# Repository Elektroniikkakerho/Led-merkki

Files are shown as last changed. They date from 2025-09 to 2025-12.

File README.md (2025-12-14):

# LED-MERKKI
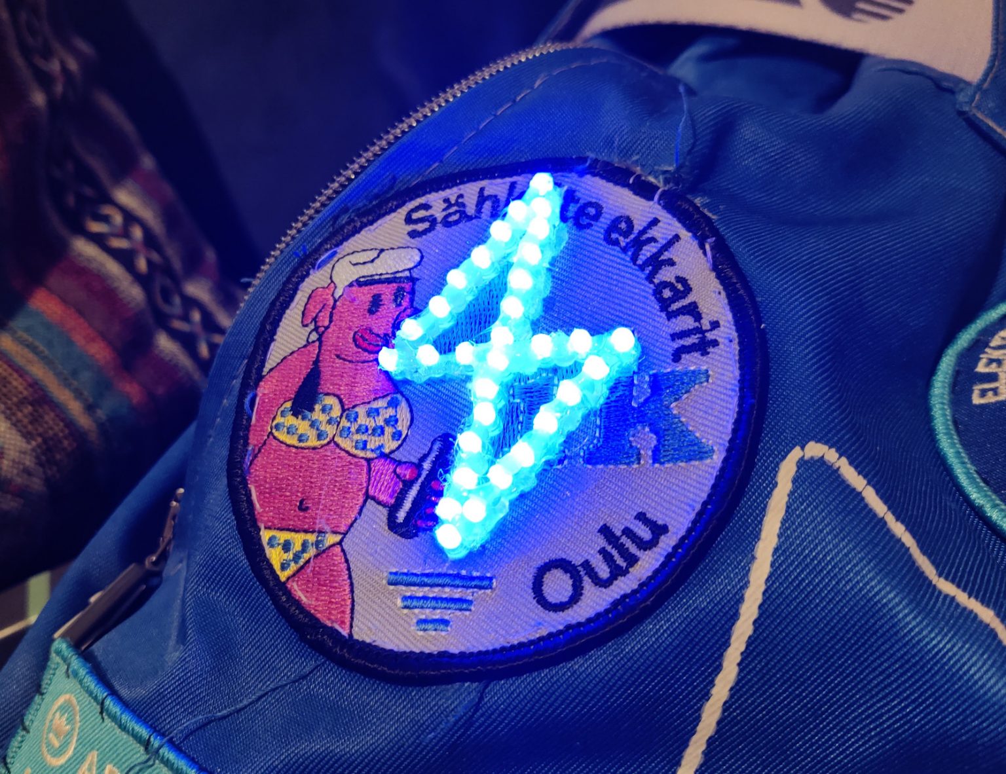
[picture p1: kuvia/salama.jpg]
Tämä kuva vaihtuu joskus gifiin 👀


## Mistä koostuu ja miten se toimii
Salaman mikrokontrolleri (mcu) ohjaa ledejä sytyttäen niitä yksi kerrallaan hyvin lyhyeksi aikaa.
Ledit ovat multiplexattu (4x8 LED), ja kytketty yhdellä vastuksella per rivi.

Levyyn on myös suunniteltu kytkin, jolla voisi vaikka sammuttaa laitteen tai toimittaa muuta toiminnallisuutta, mutta näitä ei ole koodissa toteutettu vieläkään.

Kuusipinninen liitin on ohjelmointia varten ja sitä kautta ohjelma siirretääm mikrokontrollerille.
Ohjelmointi hoituu Arduinon ISP:n kautta.

## Skeema
skeema Skema on jotakuinkin tällainen

## Osaluettelo
<!--
  * 1 kpl  ATtiny861a SOIC
  * 32 kpl 3 mm diffusoitu LED
  * 1 kpl  10 µF SMD tantaalikondensaattori
  * Kuusi pinnisen piikkiriman ohjelmointia varten.

  **Riippuen LEDien väristä:**
  * Siniset/valkoiset/vihreät:   4 kpl 110 Ohm 1206/1210 SMD-vastus
  * Punaiset/keltaiset:          4 kpl 150 Ohm...
  
  **lisäksi tarvitset:**
  * kuumaliimaa
  * USB kaapelin
  * Extra vastuksen? Selivä myöhemmin...
  * haalarimerkin :-)
-->

| **Komponetti** | **KPL** | **Huomautukset** |
| :--- | :--- | :--- |
| ATtiny861a SOIC | 1 |  |
| 3 mm diffusoitu LED | 32 | |
| 110 Ohm 1206/1210 SMD vastus | 4 | Sinisille, valkoisille, vihreille ledeille |
| 169 Ohm 1206/1210 SMD vastus | 4 | Keltaisille, punaisille ledeille |
| 10 µF SMD tantaalikondensaattori | 1 | |
| 6 pinnisen piikkirima | - | Ohjelmointia varten |
| Kuumaliimaa | - | Ledien suojaamiseen |
| USB kaapeli | - | Sopivan pituinen, vaikka 1 m |
| Haalarimerkki | 1 | :-) |

<!---
| **Komponetti** | **KPL** | **Huomautukset** |
| :--- | :--- | :--- |
| ATtiny861a SOIC | 1 | S/SU |
| 3 mm diffusoitu LED | 32 | |
| 10 µF SMD tantaalikondensaattori | 1 | |

| **Vastuksets** | **KPL** | **Huomautukset** |
 :--- | :--- | :--- |
| 110 Ohm 1206/1210 SMD vastus | 4 | Sinisille, valkoisille, vihreille ledeille |
| 150 Ohm 1206/1210 SMD vastus | 4 | Keltaisille, punaisille ledeille |
| | | | 

| **Lisäksi tarvitset** | |
 :--- | :--- |
| 6 pinnisen piikkirima | ohjelmointia varten |
| Kuumaliimaa | Ledien suojaamiseen |
| USB kaapelin | Sopivan pituinen |
| Haalarimerkin  | :-) |
--->
  
## Pirilevyt 
| [SIK](kicad/possu) | OTiT | [YRK](kicad/ymp) | [PROSE](kicad/prose) | [KONE](kicad/kone) | [ARK](kicad/ark) | [OPTIEM](kicad/optiem) |
| :---: | :---: | :---: | :---: |  :---: |  :---: |  :---: |
|   |   |   |  |  |  |  <tr></tr>
|  |  |  |  |  |   | 
<!---| <img src="kicad/kuvat/possu_läpi.svg" alt="alt" width="200">  |   |   |   | | | <tr></tr> --->

<!-- ## Ohjeet piirilevyn tekoon -->
<!-- <details> -->
<!-- <summary><b>Näytä </b></summary> -->
<!-- Tee vaikka syövyttämällä tai jyrsimällä :D -->
<!-- </details> -->

# Ohjeet kokoonpanoon

Nyt kun sinulla on piirilevy, laitetaampa siihen komponentit kiinni.

## 1. Pintaliitos komponentit

Piirilevyyn juotetaan 4 SMD vastusta, 1 SMD kondensaattori ja 6-pinninen piikkirimai.  
Helpointen ja nätein tapa juottaa ne on laittamalla yhteen pädiin vähän tinaa ja sitten     varovasti työntää komponetti sulaneseen tinaan, niin ettei se jää "ilmaan".  
Toinen puoli on helpompi juottaa kun se nyt pysyy siinä paikallaan.

Vastuksilla ei ole väliä kummin päin ne on laitettu, kuhan numero puoli on ylöspäin ja suhteellisen suoraan laitettu, se on hyvä.
Kondensaattorin suunta pitää kattoa leiskasta.

Piikkiriman juottaminen onnistuu samalla tavalla, paitsi nyt joudut pitämään sitä vähän ilmassa,  
jotta saat sen kunnolla juotettua kiinni.

## 2. Piiri 
Piirin juottaminen onnistuu helpointen siten, että juotat ensin yhden kulmajalan kiinni.  
Sulata juotos, jos piiri on vinossa.
Tarkista, että piirin kaikki jalat ovat pädien päällä. Ei ilmassa.  
Juota sitten toinen vastakkainen kulmajalma.

Loput jalat voi juottaa yksi kerrallaan.  
Tai jos haluaa kokeilla nopeammalla tavalla niin veto juottamalla saa yhden puolen yhdellä vedolla*. 
[Esimerkki video...](https://www.youtube.com/results?search_query=drag+soldering)

## 3. Virtajohto
USB kaapelista pitää leikata toinen pää pois.  
Kuori 5v and GND johdot joko saksilla tai kuorimilla.  
Juota sitten 5V ja GND piirilevyyn.

Tähän kannattaa käyttää USB-kaapelia, jossa on vain 5V ja GND.   
Tai sellaista kaapelia jossa on paksut sisäiset johtimet.

## 4. Ledit

Ledien juottaminen on suurin työmaa merkin valmistuksessa.  
Työtä aiheuttaa lähinnä ledin painaminen merkistä läpi. Ensin pitää huomioida polariteetti.  
Jos olet nähnyt paljon vaivaa että olet laittanut ledit miten sattuu niin voipi harmittaa..

**Pidä mielessä:**  
Pyöreä läpiveto ja pidempi jalka ledissä = POS  
Neliö läpiveto ja lyhyempi jalka ledissä = NEG

Ledien jalkojen päät kannattaa katkoa kulmassa, näin niistä tulee teräviä. Helpottaa ledien painamista merkistä läpi.
Toinen kikka on myös paksummalla neulalla tehä reikiä etukäteen.

Jos jostakin syystä, olet juottanut kaikki ledin väärin päin.  
Erinomaista, homma meni pieleen.  
Onneksi on olemassa toinen koodi tiedosto joka vaihtaa ledien logiikan.
   
## [5. Hyppää kohtaan "Ohjelmointi"](#ohjelmointi)
   
## 6. Piikkiriman poisto
Sitten kun ohjelmisto on flashatty ja tarkistettu, että kaikki ledit toimiii niinkuin pitäisi, piikkirima otetaan pois. Joko imusukkaa / tinapumppua käyttäen tai sitten lämmittämällä kaikki joloissa olevat tinat kolvilla, tekemällä vetoliikkeitä.
    
## 7. Kuormavastus 
Tässä kohtaan on hyvä kokeilla laittaa merkki powerbankkiin kiinni.

Jos merkki sammuu itsestään, se voi hyvinkin johtua siitä, että merkki on liian energiatehokas :D
Esim. SIK:in possu merkki syöpi n. 5-20 ma riippuen ledien tilasta.

Tämän ongelman saa korjattua juottamalla kuormavastuksen 5V ja GND väliin.  
Esim. Juottamalla 110 ohmin vastuksen, merkki syö ~60 ma.  
Tarvittava kuormavastus riippuu käyttämästäsi varavirtalähteestä.  
Niissä on vaihteleva minimivirranvaatimus, jonka alittaessa ne katkaisevat virransyötön.
    
## 8. Viimeistely
Lopuksi, laita kuumaliimaa ledien ympärille suojausta varten.  
Ei ole pakko jos et halua.

Mutta siinähän ois ***komia*** merkki valmiina.  
Ei muuta ku ompelemaan kiinni!!  
🥳 🧵 🪡

<!-- </details> -->

# Ohjelmointi

Tähän tarvitset Arduino nanon tai unon, jotta saat siirrettyä koodit levylle.

Koodin kääntämiseen tarvitset avr-gcc ja koodin siirtämiseen avrdude.  
Eli asenna omalle käyttöjärjestelmälle kyseiset työkalut, ennen seuraavia kohtia.

## 1. Ohjelmoinin setuppaus
Aletaanpa pukata sitä koodia, että merkkistä tulisi valoa.  
Mutta ensin pitää hyppyjohdoilla tehdä yhteys led-merkkiin.

Käytetään Arduino nanoa tässä esimerkissä:

| Merkin pinni | 1 | 2| 3 | 4 |5 |6 |
| :---: | :---: | :---: | :---: | :---: | :---: | :---: |
| *Selite* | *MOSI* | *MISO* | *SCK* | *VCC* | *GND* | *Reset* <tr></tr> |
| **Arduinon pinni** | **D11** | **D12**| **D13** | **VCC** | **GND** | **D10** | 

(Leiska kuvasta näkee liittimessä neliön --> 1. pinni)

Muista vetää arduinon Reset ylös. Ardu nollautuu kun sarjaliikenne alotetaan....

## 2. Ledien suunta logiikan flippaus
Mikäli olet juottanut ledit väärinpäin, eikä niiden irroittaminen ja uudelleen juottaminen huvita,  
voit muuttaa ledien ohjaavan logiikan ennen kääntämistä.
      
**Tiedosto: led-merkki/src/vilkutus.c**  
(rivit 6-7):

```c
#include "lediportit.h"             // Mikäli juotit ledit väärin päin,
// #include "lediportit_vaarin.h"   // Vaihda tästä otsikko tiedosto.
  ```
Ledit väärinpäin: 
```c
// #include "lediportit.h"             // Mikäli juotit ledit väärin päin,
#include "lediportit_vaarin.h"   // Vaihda tästä otsikko tiedosto.       
```

## 3. Koodin kääntäminen

```bash
# Kääntäminen käyttäen avr-gcc:tä
avr-gcc -mmcu=attiny861 salama.c -I./ -Os -DF_CPU=8000000UL
```

  Jos et saa koodeja käännettyä,  pre_compiled hakemistosta löytyy valmiiksi käännetyt koodit. 
    
## 4. Ohjelman siirto levylle 

#####  Unix-like

```bash
# Fläsäys käyttäen arduino-isp:tä
avrdude -c avrisp -p t861 -B3 -P /dev/ttyUSB0 -b 19200 -U flash:w:a.out

# Fuse asetukset käyttäen arduino-isp:tä
avrdude -c avrisp -p t861 -B3 -P /dev/ttyUSB0 -b 19200 -U lfuse:w:0xe2:m -U hfuse:w:0xdf:m
```
Jos valittaa oikeuksista, vedä sudo/doas tilassa.

Jos siirtämisen aikana tulee "programmer not responding",  
kokeile toista baudratea tai ottamalla "-B3" pois.

##### Windows

```bash
# Fläsäys käyttäen arduino-isp:tä
avrdude -C "C:\Program Files (x86)\Arduino\hardware\tools\avr\etc\avrdude.conf" -c avrisp -p t861 -B3 -P COM7 -b 19200 -U flash:w:a.out

# Fuse asetukset käyttäen arduino-isp:tä
avrdude -C "C:\Program Files (x86)\Arduino\hardware\tools\avr\etc\avrdude.conf" -c avrisp -p t861 -B3 -P COM7 -b 19200 -U lfuse:w:0xe2:m -U hfuse:w:0xdf:m
```
Windowsilla avrdude pitää olla ympäristömuuttujissa.  
Toinen vaihtoehto on ajaa komento "\Arduino\hardware\tools\avr\bin"-kansiossa.

## [5. Hyppää kohtaan "Piikkiriman poisto"](#6-piikkiriman-poisto)

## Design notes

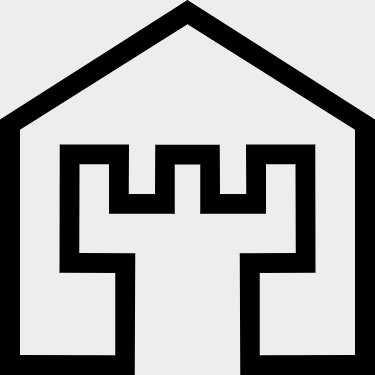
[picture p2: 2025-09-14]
kicad/ark/ark.bmp

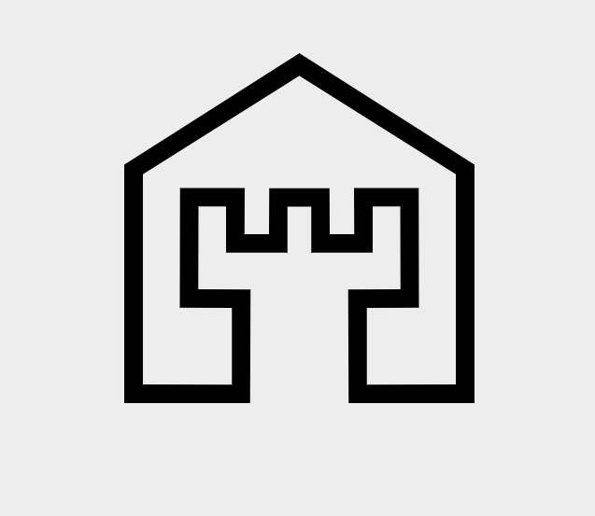
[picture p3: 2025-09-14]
kicad/ark/ark.png

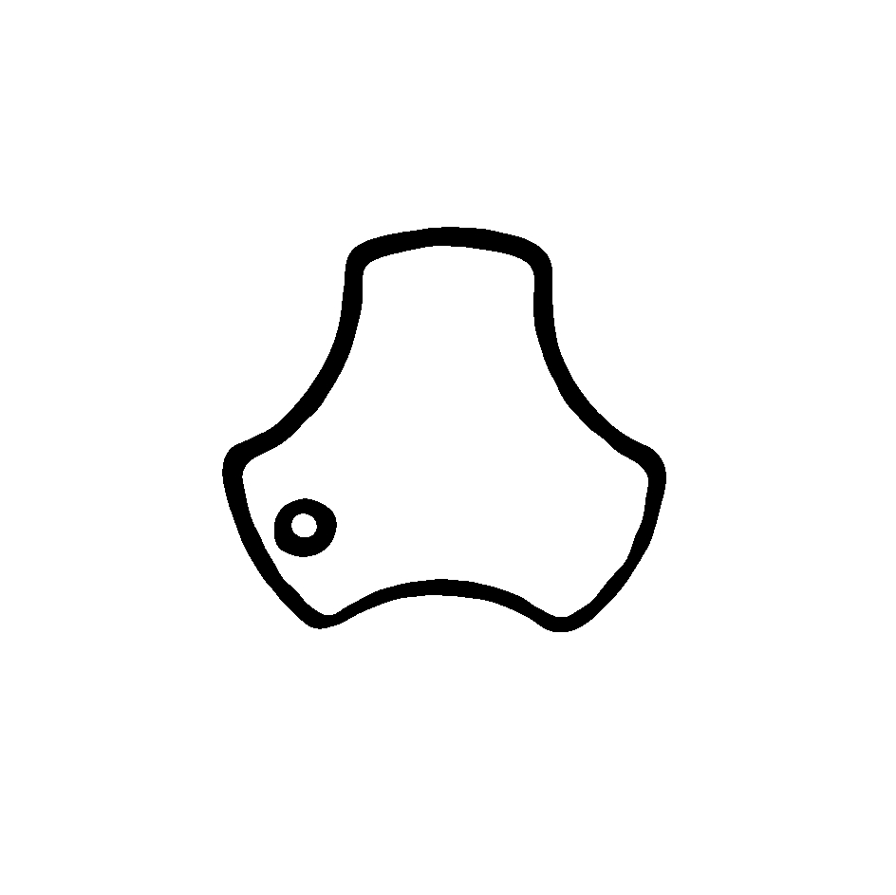
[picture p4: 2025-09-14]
kicad/kone/konekiltauusi.jpeg

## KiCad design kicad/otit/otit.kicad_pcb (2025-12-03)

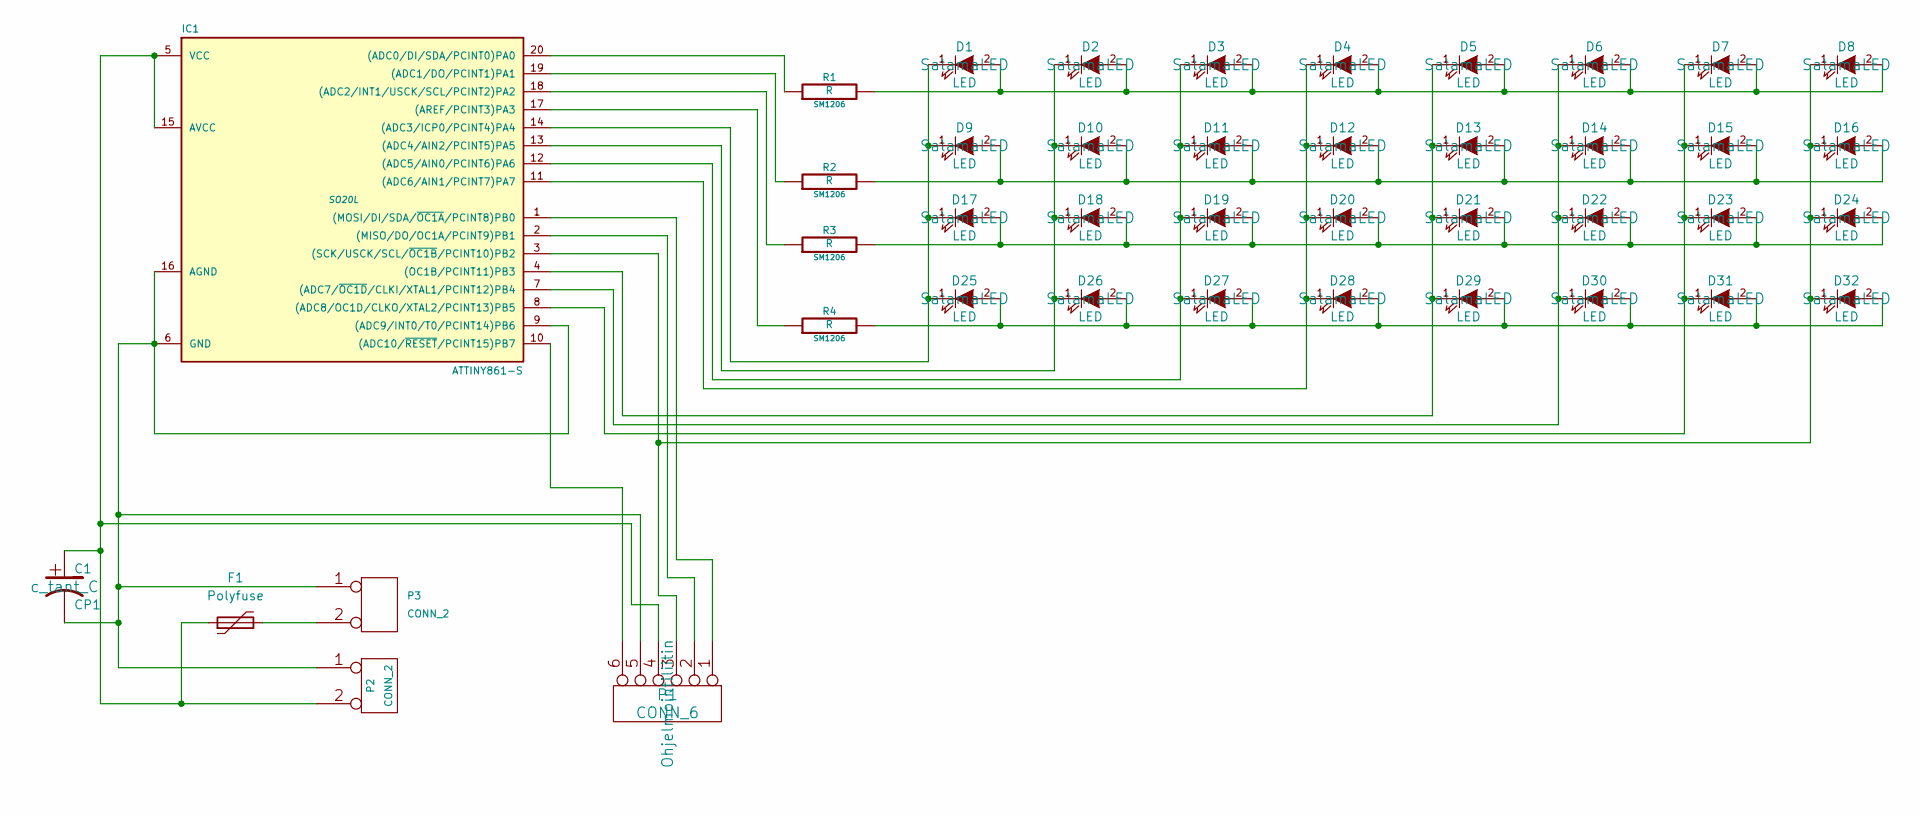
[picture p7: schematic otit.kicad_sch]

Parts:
C1: CP1; c_tant_C
D1, D2, D3, D4, D5, D6, D7, D8, D9, D10, D11, D12, D13, D14, D15, D16, D17, D18, D19, D20, D21, D22, D23, D24, D25, D26, D27, D28, D29, D30, D31, D32: LED; SalamaLED
F1: Polyfuse
IC1: ATTINY861-S; SO20L
P1: CONN_6; Ohjelmointiliitin
P2: CONN_2; Salama_virta
P3: CONN_2
R1, R2, R3, R4: R; SM1206

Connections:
unnamed: D1.2 (A), D2.2 (A), D3.2 (A), D4.2 (A), D5.2 (A), D6.2 (A), D7.2 (A), D8.2 (A), R1.2
unnamed: D1.1 (K), D9.1 (K), D17.1 (K), D25.1 (K), IC1.14 ((ADC3/ICP0/PCINT4)PA4)
unnamed: D9.2 (A), D10.2 (A), D11.2 (A), D12.2 (A), D13.2 (A), D14.2 (A), D15.2 (A), D16.2 (A), R2.2
unnamed: D2.1 (K), D10.1 (K), D18.1 (K), D26.1 (K), IC1.13 ((ADC4/AIN2/PCINT5)PA5)
unnamed: D3.1 (K), D11.1 (K), D19.1 (K), D27.1 (K), IC1.12 ((ADC5/AIN0/PCINT6)PA6)
unnamed: D4.1 (K), D12.1 (K), D20.1 (K), D28.1 (K), IC1.11 ((ADC6/AIN1/PCINT7)PA7)
unnamed: D5.1 (K), D13.1 (K), D21.1 (K), D29.1 (K), IC1.4 ((OC1B/PCINT11)PB3)
unnamed: D6.1 (K), D14.1 (K), D22.1 (K), D30.1 (K), IC1.7 ((ADC7/~OC1D/CLKI/XTAL1/PCINT12)PB4)
unnamed: D7.1 (K), D15.1 (K), D23.1 (K), D31.1 (K), IC1.8 ((ADC8/OC1D/CLKO/XTAL2/PCINT13)PB5)
unnamed: D8.1 (K), D16.1 (K), D24.1 (K), D32.1 (K), IC1.3 ((SCK/USCK/SCL/~OC1B/PCINT10)PB2), P1.3
unnamed: D17.2 (A), D18.2 (A), D19.2 (A), D20.2 (A), D21.2 (A), D22.2 (A), D23.2 (A), D24.2 (A), R3.2
unnamed: D25.2 (A), D26.2 (A), D27.2 (A), D28.2 (A), D29.2 (A), D30.2 (A), D31.2 (A), D32.2 (A), R4.2
unnamed: F1.2, P3.2 (PM)
unnamed: IC1.20 ((ADC0/DI/SDA/PCINT0)PA0), R1.1
unnamed: IC1.19 ((ADC1/DO/PCINT1)PA1), R2.1
unnamed: IC1.18 ((ADC2/INT1/USCK/SCL/PCINT2)PA2), R3.1
unnamed: C1.2, IC1.6 (GND), IC1.9 ((ADC9/INT0/T0/PCINT14)PB6), IC1.16 (AGND), P1.5, P2.1, P3.1
unnamed: IC1.10 ((ADC10/~RESET/PCINT15)PB7), P1.6
unnamed: IC1.17 ((AREF/PCINT3)PA3), R4.1
unnamed: IC1.2 ((MISO/DO/OC1A/PCINT9)PB1), P1.2
unnamed: IC1.1 ((MOSI/DI/SDA/~OC1A/PCINT8)PB0), P1.1
unnamed: C1.1, F1.1, IC1.5 (VCC), IC1.15 (AVCC), P1.4, P2.2 (PM)

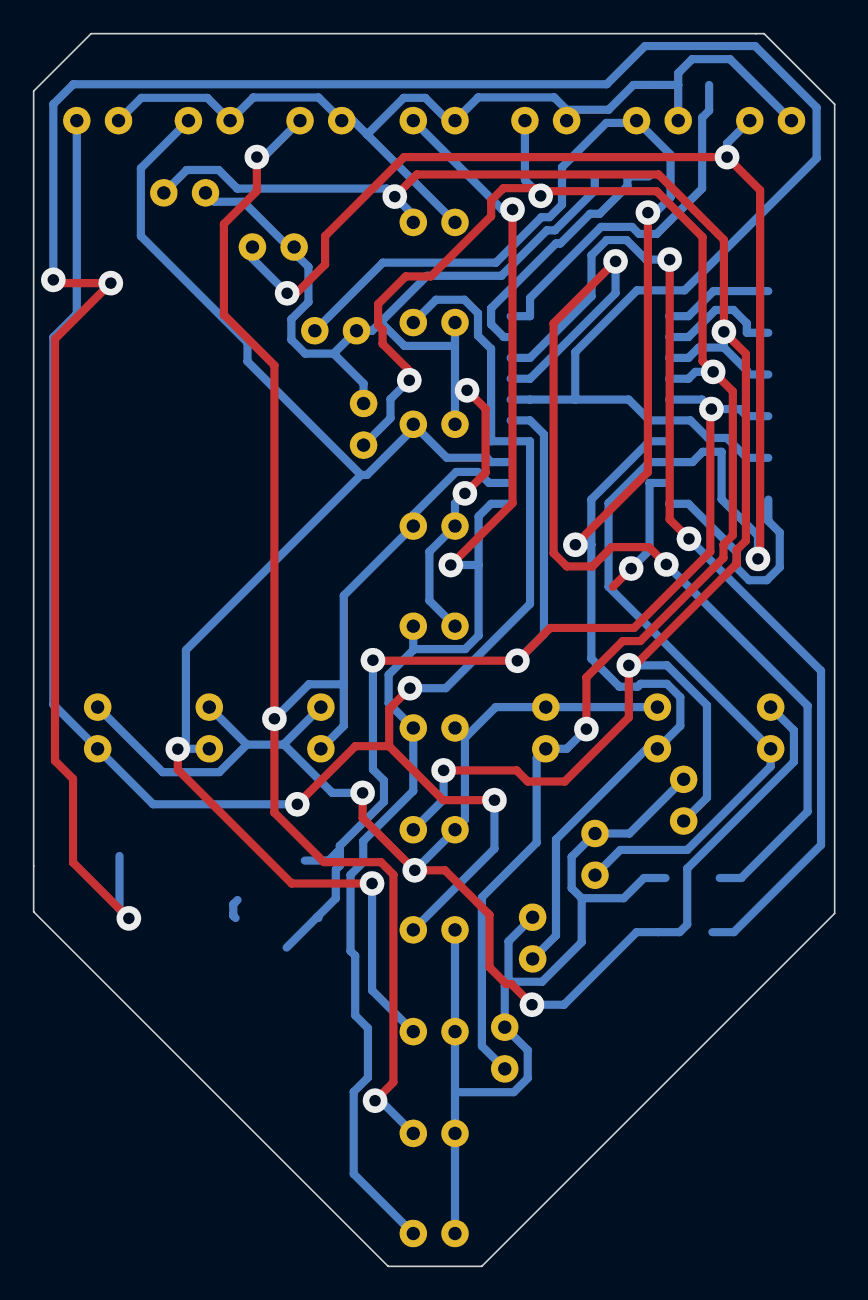
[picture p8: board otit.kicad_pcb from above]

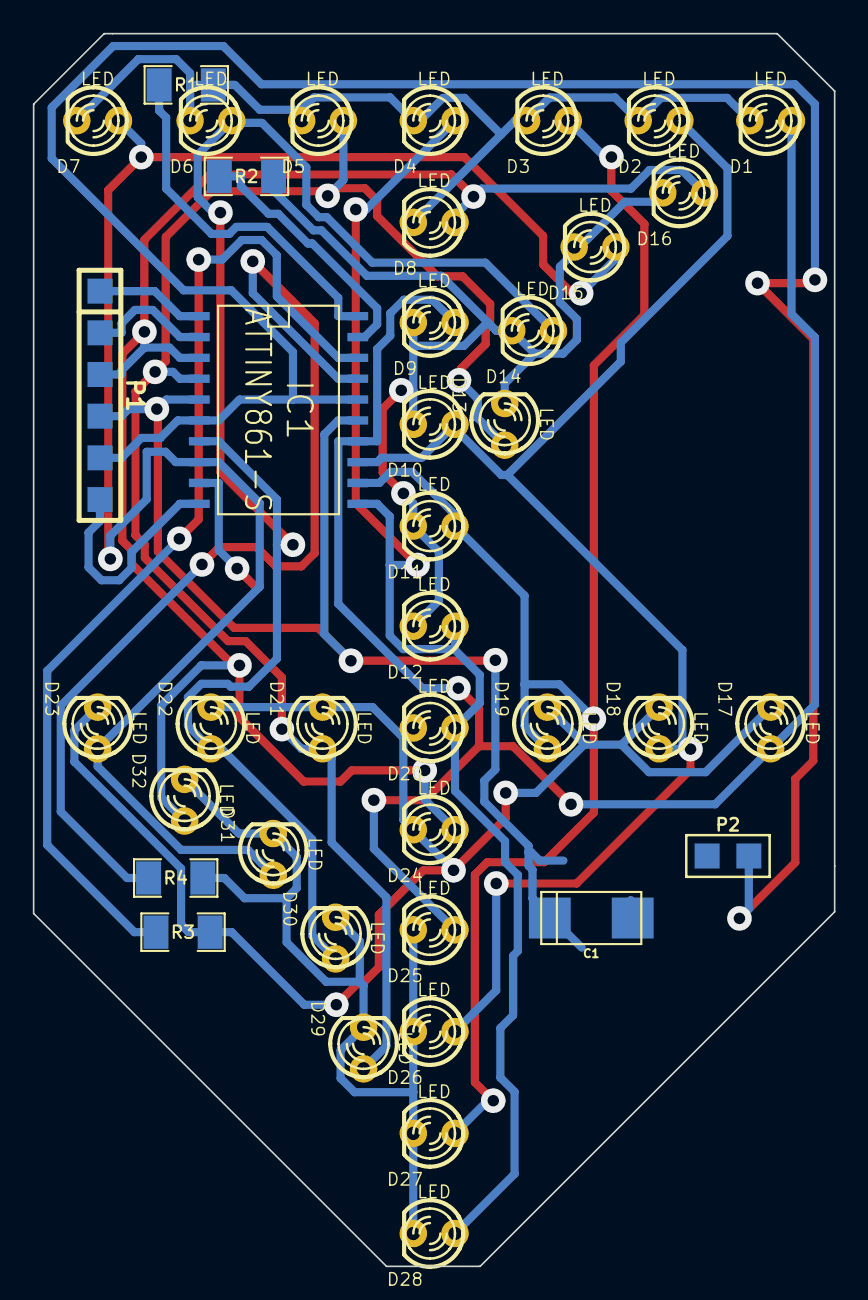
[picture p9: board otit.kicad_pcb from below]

Board: 2 copper layers, 48.8 x 75.1 mm, 40 parts (40 on the bottom side), 21 nets.

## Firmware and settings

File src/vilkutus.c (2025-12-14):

#include <avr/io.h>
#include <util/delay.h>

#include "vilkutus.h"

#include "lediportit.h"             // Mikäli juotit ledit väärin päin,
// #include "lediportit_vaarin.h"   // Vaihda tästä otsikko tiedosto.


///     K0 0
#define K1 0.001
#define K2 0.2
#define K3 1
#define K4 2
#define K5 4
#define K6 8
#define K7 14
#define K8 27
#define K9 50
#define K10 80
#define K11 110
#define K12 160
#define K13 200
#define K14 250
#define K15 312

///pimeä vaihe
#define P0 312
#define P1 312-K1
#define P2 312-K2
#define P3 312-K3
#define P4 312-K4
#define P5 312-K5
#define P6 312-K6
#define P7 312-K7
#define P8 312-K8
#define P9 312-K9
#define P10 312-K10
#define P11 312-K11
#define P12 312-K12
#define P13 312-K13
#define P14 312-K14
#define P15 0



int8_t kirkkaus[32] = {0};
//uint8_t kirkkaus[32] = {0x1,0x1,0x1,0x1,0x1,   0x1,0x1,0x1,0x1,0x1,   0x1,0x1,0x1,0x1,0x1,  0x1,0x1,0x1,0x1,0x1,  0x1,0x1,0x1,0x1,0x1,   0x1,0x1,0x1,0x1,0x1, 0x1,0x1};

/*
void tauko(uint16_t ctr)
   {
   while (ctr != 0)  
      {
      asm volatile("nop"); 
      ctr--;
      }

   }

void tauko2(uint16_t ctr)
   {
   while (ctr != 0)
      {
      _delay_ms(1);
      ctr--;
      }
   }
*/
void vilkutus(void)
{
   uint8_t led = 0;
   uint8_t *kirkptr;
   uint8_t *paptr;
   uint8_t *pbptr;
   kirkptr = &kirkkaus[0]; //kirkkaustaulukon pointteri
   paptr = &pa[0]; //PortA taulukon pointteri
   pbptr = &pb[0];
   while (led < 32)
   {
      switch (*kirkptr)
         {
         case 0:
            break;
         case 1:
            PORTA = *paptr;
            PORTB = *pbptr;
            _delay_us(K1);
            PORTA = alloff_pa;
            PORTB = alloff_pb;

            break;
         case 2:
            PORTA = *paptr;
            PORTB = *pbptr;
            _delay_us(K2);
            PORTA = alloff_pa;
            PORTB = alloff_pb;
            break;
         case 3:
            PORTA = *paptr;
            PORTB = *pbptr;
            _delay_us(K3);
            PORTA = alloff_pa;
            PORTB = alloff_pb;
            break;
         case 4:
            PORTA = *paptr;
            PORTB = *pbptr;
            _delay_us(K4);
            PORTA = alloff_pa;
            PORTB = alloff_pb;
            break;
         case 5:
            PORTA = *paptr;
            PORTB = *pbptr;
            _delay_us(K5);
            PORTA = alloff_pa;
            PORTB = alloff_pb;
            break;
         case 6:
            PORTA = *paptr;
            PORTB = *pbptr;
            _delay_us(K6);
            PORTA = alloff_pa;
            PORTB = alloff_pb;
            break;
         case 7:
            PORTA = *paptr;
            PORTB = *pbptr;
            _delay_us(K7);
            PORTA = alloff_pa;
            PORTB = alloff_pb;
            break;
         case 8:
            PORTA = *paptr;
            PORTB = *pbptr;
            _delay_us(K8);
            PORTA = alloff_pa;
            PORTB = alloff_pb;
            break;
         case 9:
            PORTA = *paptr;
            PORTB = *pbptr;
            _delay_us(K9);
            PORTA = alloff_pa;
            PORTB = alloff_pb;
            break;
         case 10:
            PORTA = *paptr;
            PORTB = *pbptr;
            _delay_us(K10);
            PORTA = alloff_pa;
            PORTB = alloff_pb;
            break;
         case 11:
            PORTA = *paptr;
            PORTB = *pbptr;
            _delay_us(K11);
            PORTA = alloff_pa;
            PORTB = alloff_pb;
            break;
         case 12:
            PORTA = *paptr;
            PORTB = *pbptr;
            _delay_us(K12);
            PORTA = alloff_pa;
            PORTB = alloff_pb;
            break;
         case 13:
            PORTA = *paptr;
            PORTB = *pbptr;
            _delay_us(K13);
            PORTA = alloff_pa;
            PORTB = alloff_pb;
            break;
         case 14:
            PORTA = *paptr;
            PORTB = *pbptr;
            _delay_us(K14);
            PORTA = alloff_pa;
            PORTB = alloff_pb;
            break;
         case 15:
            PORTA = *paptr;
            PORTB = *pbptr;
            _delay_us(K15);
            PORTA = alloff_pa;
            PORTB = alloff_pb;
            break;
         default: // negatiiviset ajatellaan nolliksi
            break;
         }

      kirkptr++;
      paptr++;
      pbptr++;
      led++;
   }

   ///sammuttelu ja venailu

   PORTA = alloff_pa;
   PORTB = alloff_pb;
   //PORTA = pa[16];
   //PORTB = pb[16];
   led = 0;
   kirkptr = &kirkkaus[0]; //kirkkaustaulukon pointteri
   while (led < 32)
      {
      switch (*kirkptr)
         {
         case 0:
            _delay_us(P0);
            break;
         case 1:
            _delay_us(P1);
            break;
         case 2:
            _delay_us(P2);
            break;
         case 3:
            _delay_us(P3);
            break;
         case 4:
            _delay_us(P4);
            break;
         case 5:
            _delay_us(P5);
            break;
         case 6:
            _delay_us(P6);
            break;
         case 7:
            _delay_us(P7);
            break;
         case 8:
            _delay_us(P8);
            break;
         case 9:
            _delay_us(P9);
            break;
         case 10:
            _delay_us(P10);
            break;
         case 11:
            _delay_us(P11);
            break;
         case 12:
            _delay_us(P12);
            break;
         case 13:
            _delay_us(P13);
            break;
         case 14:
            _delay_us(P14);
            break;
         case 15:
            _delay_us(P15);
            break;
         default:
            _delay_us(P15);
            break;
         }
      kirkptr++;
      led++;
      }
   }

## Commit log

2025-09-19 README.md Päivitys
    Update README.md
    Update README.md
    Update README.md
    Lisätty muitten kiltojen gerbereita
    rename dirs
    Update README.md
    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
    [ark-B_Cu.gbl, ark-B_Mask.gbs, ark-Edge_Cuts.gm1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]
2025-12-03 Kicadi projekti tiedostoja siirretty omiin kansioihin
    [ark-B_Cu.gbl, ark-B_Mask.gbs, ark-Edge_Cuts.gm1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]
